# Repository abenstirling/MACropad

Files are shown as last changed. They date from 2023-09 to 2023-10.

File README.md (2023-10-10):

# MACropad
#### Open-Source Macropad, in form factor of the iconic Apple Computer Macintosh. 
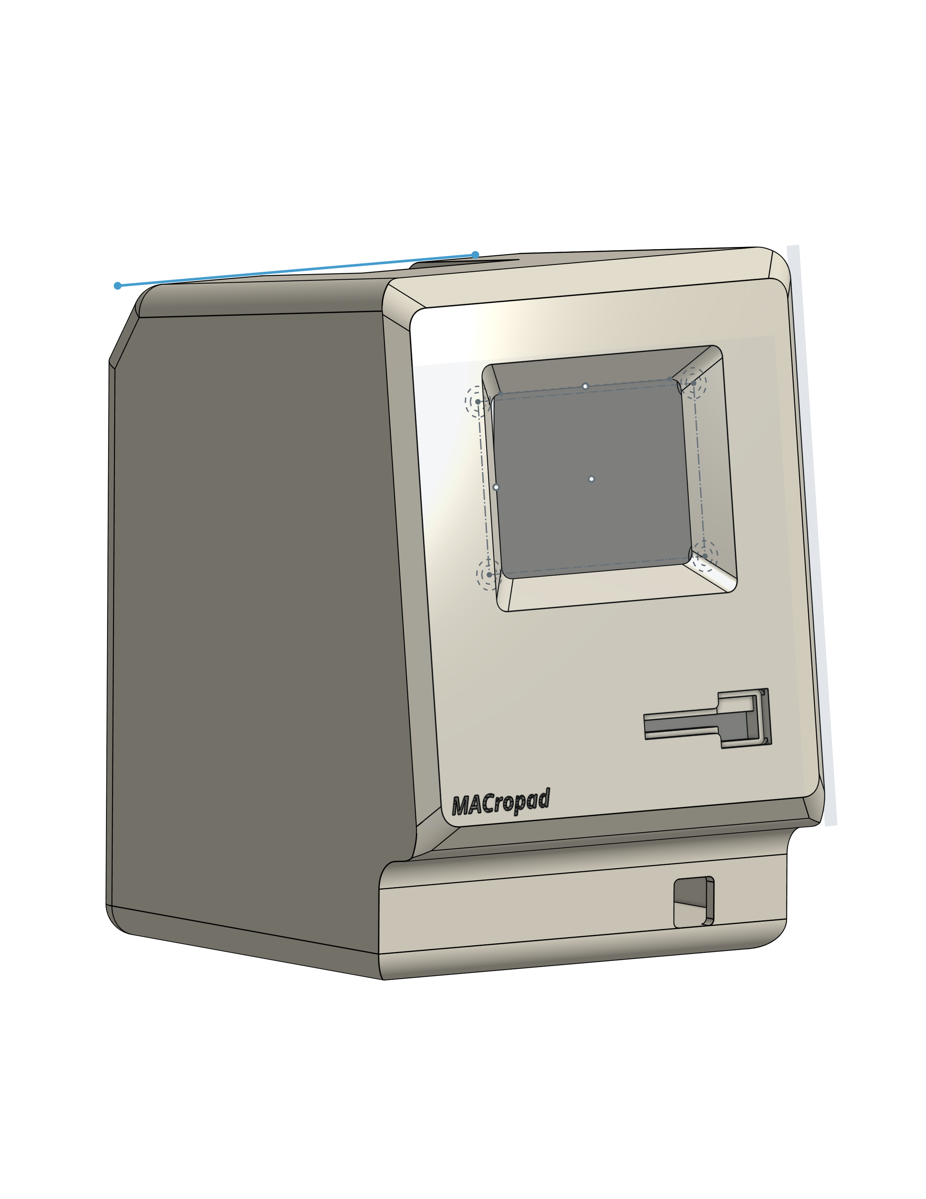
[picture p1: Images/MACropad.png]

### Functionality
---
- 6 Customizable Keys
- 2 Rotary Encoders
- RGB-powered Lights
- eInk Display

### Hardware
---
- Custom PCB, powered by the RPI Pico
- 3D Printed Case
- Headphone Jack UART Communication between MAC and Pad

### Software
---
- Embedded Rust

### Repo Structured as follows: 
```
MACropad
├── Firmware
│   ├── Cargo.toml
│   ├── Cargo.lock
│   ├── src
│   │   ├── main.rs
│   │   ├── lib.rs
│   │   ├── rotary.rs
│   │   ├── key.rs
│   │   ├── display.rs
│   │   ├── led.rs
│   │   ├── uart.rs
│   │   ├── usb.rs
│   │   ├── usb_desc.rs
│   │   ├── usb_strings.rs
├── ECAD
│   ├── MACropad.gerber
│   ├── MACropad.bom
├── MCAD
│   ├── case.step
│   ├── case.stl
│   ├── case.gcode
├── Images
│   ├── MACropad.png
├── LICENSE
├── README.md
├── .gitignore

```

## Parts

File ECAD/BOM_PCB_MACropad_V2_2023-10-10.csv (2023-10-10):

ID | Name | Designator | Footprint | Quantity | Manufacturer Part | Manufacturer | Supplier | Supplier Part | Price | 3DModel | Contributor
1 | 100k | R1 | R0603 | 1 |  |  |  |  |  | R0603 | LCEDA_Lib
2 | 5k1 | R2,R3 | R0603 | 2 |  |  |  |  |  | R0603 | LCEDA_Lib
3 | EC11E15204A3 | SW1,SW2 | SW-TH_EC11XXXXXXXX | 2 | EC11E15204A3 | ALPSALPINE(阿尔卑斯阿尔派) | LCSC | C470710 | 1.758 | SW-TH_EC11XXXXXXXX-L11.7-W12.0-H24.5-P2.5-LS14.5 | LCSC
4 | CherryMX | SW3 | CHERRYMX | 1 |  | Cherry |  |  |  | SW_CHERRY_MX | gmajosi1
5 | CherryMX | SW4,SW5,SW6,SW7,SW8 | CHERRYMX | 5 |  | Cherry |  |  |  |  | gmajosi1
6 | PICO_TP_Exposed | U1,U2 | COMM-SMD_L51.0-W21.0-P2.54_SC0916_TP23 | 2 | PICO | Raspberry Pi(树莓派) | LCSC | C7203002 | 4.658 |  | Benjamin Stirling
7 | NO | U3,U4 | CUI_SJ2-3574A-SMT-TR | 2 |  |  |  |  |  |  | rckr
8 | SK6812 | U5,U6,U7,U8 | SK6812 | 4 | SK6812 | null |  |  |  | LED-SMD_4P-L5.0-W5.0-H1.6-P3.2 | joshward9182
9 | 1.54inch e-Paper | U9 | 1.54INCH E-PAPER | 1 | 1.54inch e-Paper | Waveshare | www.bastelgarage.ch | 420424 |  |  | JuergL
10 | 3PINS | U10,U11 | 3PINS | 2 |  |  |  |  |  |  | Chinz
11 | NO | U12 | SOIC-14_L8.7-W3.9-P1.27-LS6.0-BL | 1 | SN74AHCT125DR | TI | LCSC | C155176 | 0.211 | SOIC-14_L8.6-W3.9-H1.8-LS6.0-P1.27 | njbv23
12 | USB4085-GF-A | USB1 | USC-C-SMD_USB4085-GF-A | 1 | USB4085-GF-A | null | LCSC | C9900013983 |  | USC-C-SMD_USB4085-GF-A | lcsc

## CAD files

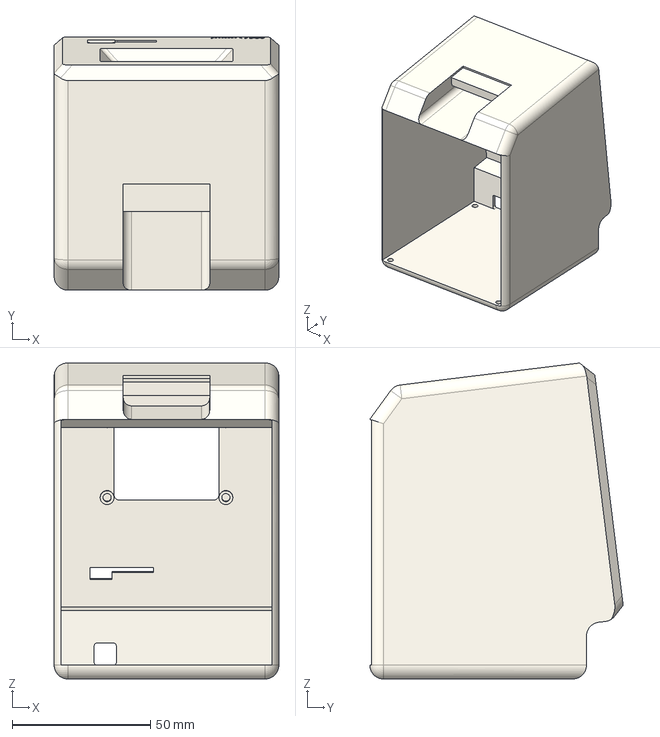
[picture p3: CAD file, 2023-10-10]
MCAD/case.step
81.3 x 91.7 x 114.4 mm

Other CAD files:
MCAD/case.stl

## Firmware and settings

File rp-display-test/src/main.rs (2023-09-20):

//! Blinks the LED on a Pico board
//!
//! This will blink an LED attached to GP25, which is the pin the Pico uses for the on-board LED.
#![no_std]
#![no_main]

use bsp::{entry, hal::gpio::FunctionSpi};
use defmt::*;
use defmt_rtt as _;
use embedded_graphics::{
    draw_target::DrawTarget,
    mono_font::MonoTextStyleBuilder,
    prelude::*,
    primitives::PrimitiveStyleBuilder,
    text::{Baseline, Text, TextStyleBuilder},
    Drawable,
};
use embedded_hal::digital::v2::OutputPin;
use panic_probe as _;

// Provide an alias for our BSP so we can switch targets quickly.
// Uncomment the BSP you included in Cargo.toml, the rest of the code does not need to change.
use bsp::hal;
use rp_pico as bsp;
// use sparkfun_pro_micro_rp2040 as bsp;

use cortex_m::prelude::*;
use fugit::RateExtU32;

use epd_waveshare::{epd1in54_v2::Display1in54, epd1in54_v2::Epd1in54, prelude::*};

use bsp::hal::{
    clocks::{init_clocks_and_plls, Clock},
    pac,
    sio::Sio,
    watchdog::Watchdog,
};

#[entry]
fn main() -> ! {
    info!("Program start");
    let mut pac: pac::Peripherals = pac::Peripherals::take().unwrap();
    let core = pac::CorePeripherals::take().unwrap();
    let mut watchdog = Watchdog::new(pac.WATCHDOG);
    let sio = Sio::new(pac.SIO);

    let clocks = hal::clocks::init_clocks_and_plls(
        bsp::XOSC_CRYSTAL_FREQ,
        pac.XOSC,
        pac.CLOCKS,
        pac.PLL_SYS,
        pac.PLL_USB,
        &mut pac.RESETS,
        &mut watchdog,
    )
    .ok()
    .unwrap();

    // Set the pins to their default state
    let pins = hal::gpio::Pins::new(
        pac.IO_BANK0,
        pac.PADS_BANK0,
        sio.gpio_bank0,
        &mut pac.RESETS,
    );

    let _ = pins.gpio2.into_mode::<FunctionSpi>();
    let _ = pins.gpio3.into_mode::<FunctionSpi>();
    let _ = pins.gpio4.into_mode::<FunctionSpi>();

    let spi = hal::spi::Spi::<_, _, 8>::new(pac.SPI0);

    let mut spi = spi.init(
        &mut pac.RESETS,
        clocks.peripheral_clock.freq(),
        //4.MHz(),
        //4_000_000u32.Hz(),
        115_200u32.Hz(),
        &embedded_hal::spi::MODE_0,
    );
    info!("Got SPI");

    let mut cs_pin = pins.gpio11.into_push_pull_output();
    cs_pin.set_high().unwrap();

    let busy_in = pins.gpio9.into_pull_up_input();
    let dc = pins.gpio8.into_push_pull_output();
    let mut rst = pins.gpio6.into_push_pull_output();
    info!("Got pins");

    let mut delay = cortex_m::delay::Delay::new(core.SYST, clocks.system_clock.freq().to_Hz());
    info!("Got delay");

    rst.set_high().unwrap();
    // Setup EPD
    let mut epd = Epd1in54::new(&mut spi, cs_pin, busy_in, dc, rst, &mut delay, None).unwrap();
    info!("made epd");
    epd.set_lut(&mut spi, &mut delay, Some(RefreshLut::Quick))
        .unwrap();
    // Use display graphics from embedded-graphics
    let _display = Display1in54::default();
    info!("made display");

    info!("Constructed display");

    // Use embedded graphics for drawing a line
    epd.wake_up(&mut spi, &mut delay).unwrap();
    info!("woke display");

    // Clear the full screen
    epd.clear_frame(&mut spi, &mut delay).unwrap();
    epd.display_frame(&mut spi, &mut delay).unwrap();
    info!("cleared an initial display");

    // Speeddemo
    epd.set_lut(&mut spi, &mut delay, Some(RefreshLut::Quick))
        .unwrap();
    let small_buffer = [Color::Black.get_byte_value(); 32]; //16x16
    let number_of_runs = 1;
    for i in 0..number_of_runs {
        let offset = i * 8 % 150;
        epd.update_partial_frame(
            &mut spi,
            &mut delay,
            &small_buffer,
            25 + offset,
            25 + offset,
            16,
            16,
        )
        .unwrap();
        epd.display_frame(&mut spi, &mut delay).unwrap();
    }

    // Clear the full screen
    epd.clear_frame(&mut spi, &mut delay).unwrap();
    epd.display_frame(&mut spi, &mut delay).unwrap();

    // Draw some squares

    let small_buffer = [Color::Black.get_byte_value(); 3200]; //160x160
    epd.update_partial_frame(&mut spi, &mut delay, &small_buffer, 20, 20, 160, 160)
        .unwrap();

    let small_buffer = [Color::White.get_byte_value(); 800]; //80x80
    epd.update_partial_frame(&mut spi, &mut delay, &small_buffer, 60, 60, 80, 80)
        .unwrap();

    let small_buffer = [Color::Black.get_byte_value(); 8]; //8x8
    epd.update_partial_frame(&mut spi, &mut delay, &small_buffer, 96, 96, 8, 8)
        .unwrap();

    // Display updated frame
    epd.display_frame(&mut spi, &mut delay).unwrap();
    delay.delay_ms(5000u32);

    // Display updated frame
    epd.display_frame(&mut spi, &mut delay).unwrap();
    info!("drew squares");
    delay.delay_ms(50000_u32);

    info!("sleeping display...");
    // Set the EPD to sleep
    epd.sleep(&mut spi, &mut delay).unwrap();

    loop {
        // info!("on!");
        // led_pin.set_high().unwrap();
        // delay.delay_ms(100);
        // info!("off!");
        // led_pin.set_low().unwrap();
        // delay.delay_ms(100);
    }
}

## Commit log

2023-09-20 More KiCAD
    [pcb.kicad_pcb, pcb.kicad_sch]
2023-09-21 Changes on MACmini
    [pcb.kicad_sch]
2023-09-21 Adding footprint/symbol
2023-09-22 Schematic Donezo
    [pcb.kicad_pcb, pcb.kicad_sch]
2023-10-10 ECAD, MCAD completed
    [BOM_PCB_MACropad_V2_2023-10-10.csv, case.step, case.stl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]
